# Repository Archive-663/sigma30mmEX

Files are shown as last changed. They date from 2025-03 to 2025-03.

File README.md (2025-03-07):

# Lot no. 018 | Sigma 30mm f1.4 HSM EX Canon EF Mount Conversion

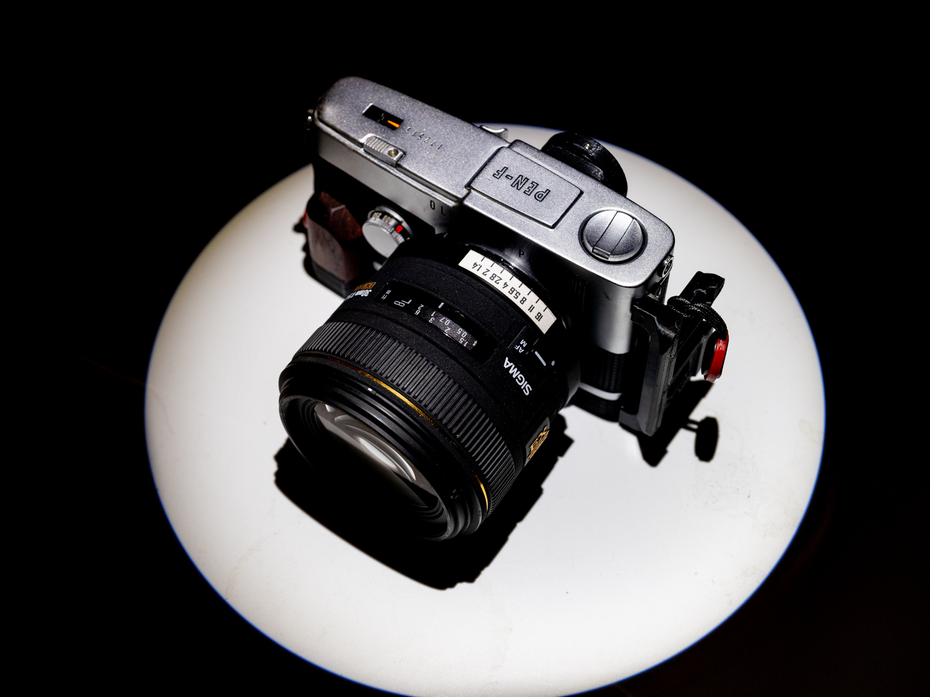
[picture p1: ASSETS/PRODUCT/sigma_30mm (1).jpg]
productShot001

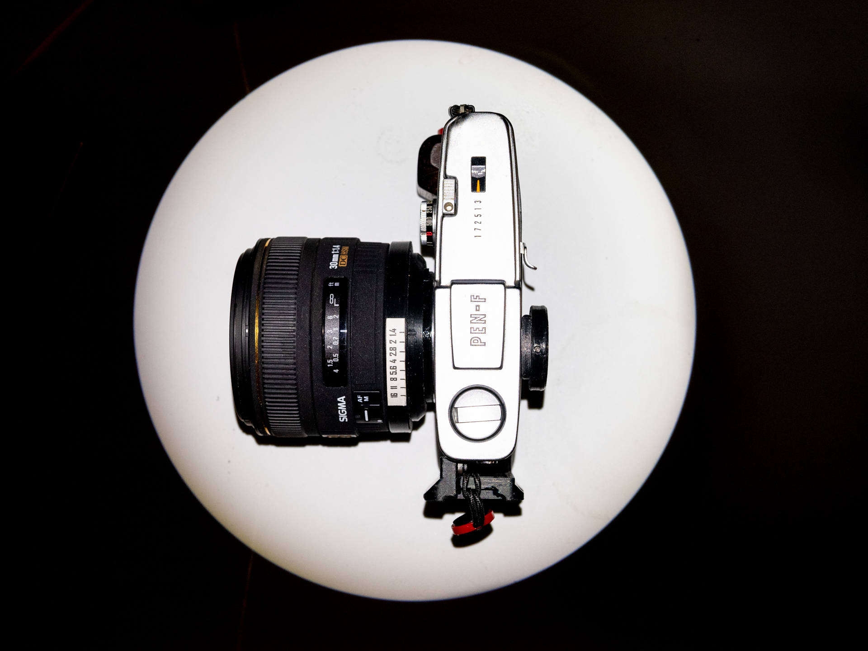
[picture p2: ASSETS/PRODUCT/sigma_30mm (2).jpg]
productShot002


### In this repository:
- Sigma 30mm f1.4 EX HSM Canon EF Aperture Control and Mount Conversion

### Background Story:
My preferred FOV for everyday photography is around 42-45mm. People keep telling me it's the most natural FOV to match our eye's FOV. Yes, we see a lot peripherally, but the main content lies within that 42-45mm FOV on a 135 camera. I've read very good reviews of the 30mm f1.4 EX HSM and I had one on hand from trying to push the low light capabilities of my GH5 with a speedbooster. These days my GH5 has a Rokinon 21mm f1.4 lens stuck to it or the 12-40mm when I need that zoom. In my search for the perfect lens for my Olympus PEN-F half frame camera, I was using an old 28mm f4 for it's size, but I wanted better low light performance as well as wonderful rendering.

Which leads us here. I took apart the Sigma 30mm and drafted some parts to mate to the iris to allow me to control it manually. Then added a PEN-F mount at the approximate correct distance to register inifinity. After getting acceptable focus, I did a quick and dirty F-stop identification mounting the lens on my Sony A7RII and added detents on the lens for these stops. I find 3D printed numbers/lettering pretty bad so I just made a label with the f-stops using the arc length between the stops and the overall throw of the iris. 

I love it so much. It's super sharp on half frame -- something I've found hard to realize with half frame. It's a little unwieldly with the large size of the 30mm but the results are worth it for me.

### What you'll need:
- 9-13x M1.6 x 5mm pan head screws (PETG) or self-tappin screws (ABS or PETG)
- 1x M1.6 tap

### What would be helpful:
- M1.4 drill bit
- M1.8/M2 drill bit
- Micro files
- PTFE synthetic grease

### Printing help:
Filament recommendation:
- ABS
- PETG

Generally, all my designs have chamfers on the print face of the STL. You can reference the supplied 'printOrientationFile.3mf' files for suggested print orientation.

### Assembly help:
Drill holes to their correct tap size before tapping.
- M1.6 requires M1.4 bore followed by an M1.6 tap.
- M1.8 or M2 bore for screw holes that aren't tapped.

Test fit before assembling. Will need to file parts to allow free movement. 

Lightly grease the inside of the mount where the aperture clutch runs.

To assemble correctly, please view the _assembly.stp file for help in parts orientation. If you do not have a CAD program, <a href="https://www.freecad.org/downloads.php" target="_blank">download FreeCAD</a> to view the assembly file and better understand how it should assemble. If using FreeCAD, the naming conventions should carry over and you will be able to see which lens element you need from the various smartphone lenses. (Verified in FreeCAD 0.18) If using something like Solid Edge open the file as an assembly to retain the names of the parts.

### Help support Archive 663 with a dontation or monthly sub



### Samples

#### Film
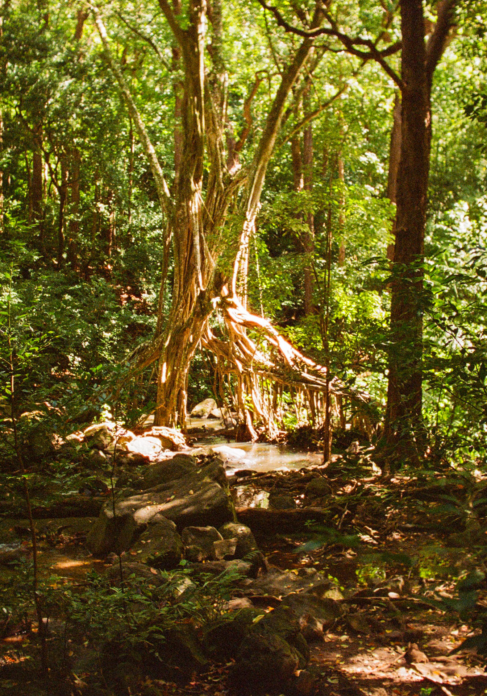
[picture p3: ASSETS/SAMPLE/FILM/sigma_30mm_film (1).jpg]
sampleFilmShot001

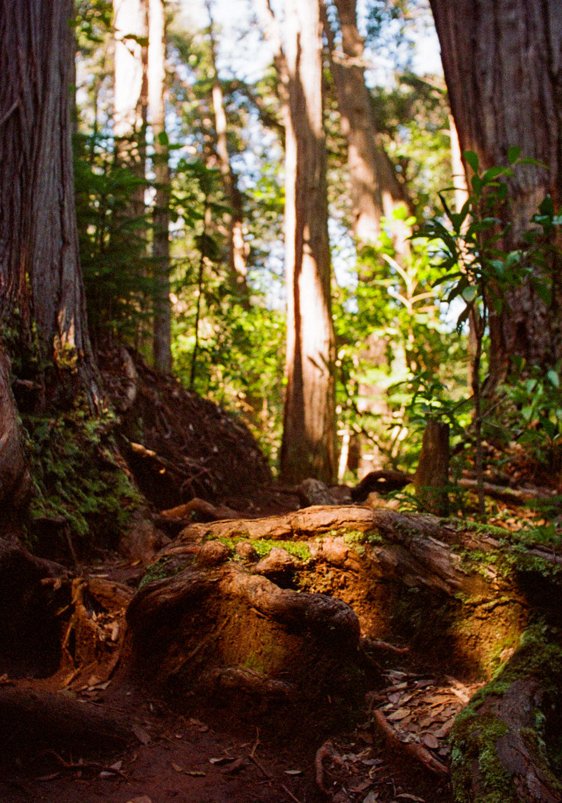
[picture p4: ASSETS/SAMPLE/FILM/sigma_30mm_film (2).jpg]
sampleFilmShot002

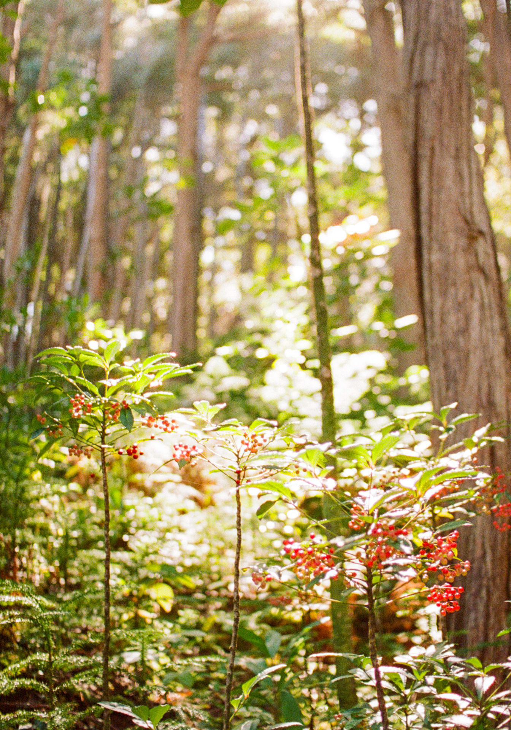
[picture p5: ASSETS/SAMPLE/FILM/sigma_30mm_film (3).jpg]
sampleFilmShot003

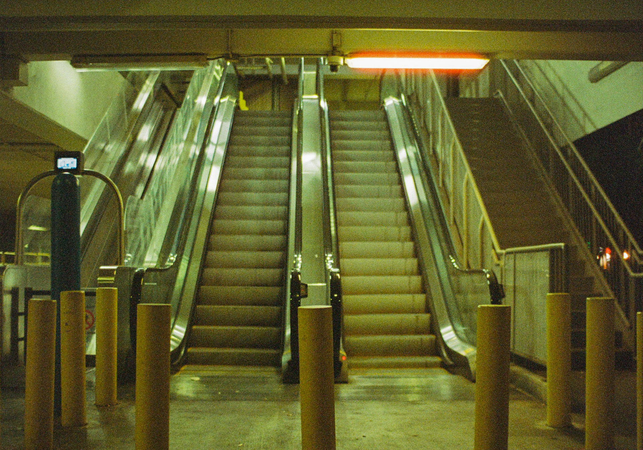
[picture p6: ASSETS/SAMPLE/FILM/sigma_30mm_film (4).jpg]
sampleFilmShot004

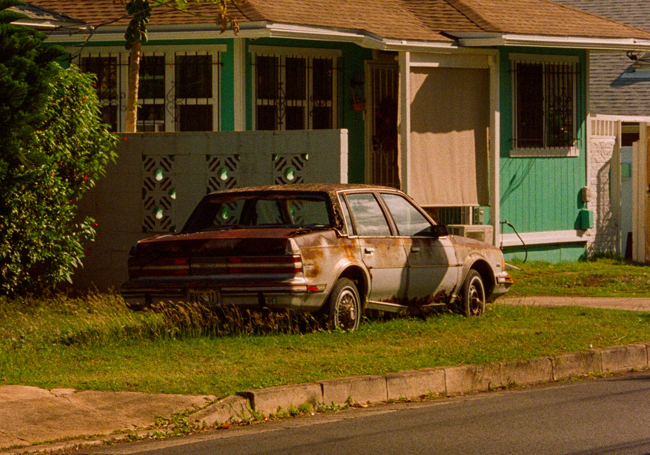
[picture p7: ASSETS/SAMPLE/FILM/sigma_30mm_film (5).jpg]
sampleFilmShot005

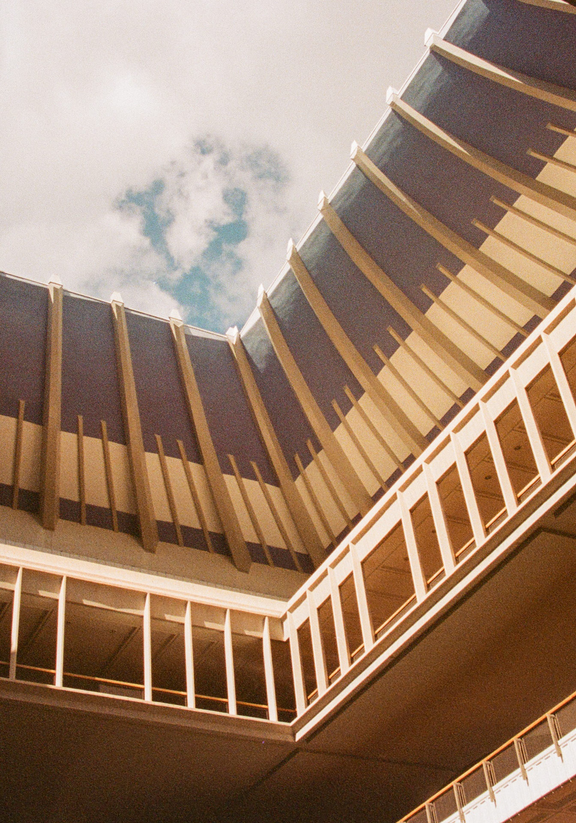
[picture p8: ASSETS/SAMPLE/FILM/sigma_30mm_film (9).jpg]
sampleFilmShot009


#### Digital
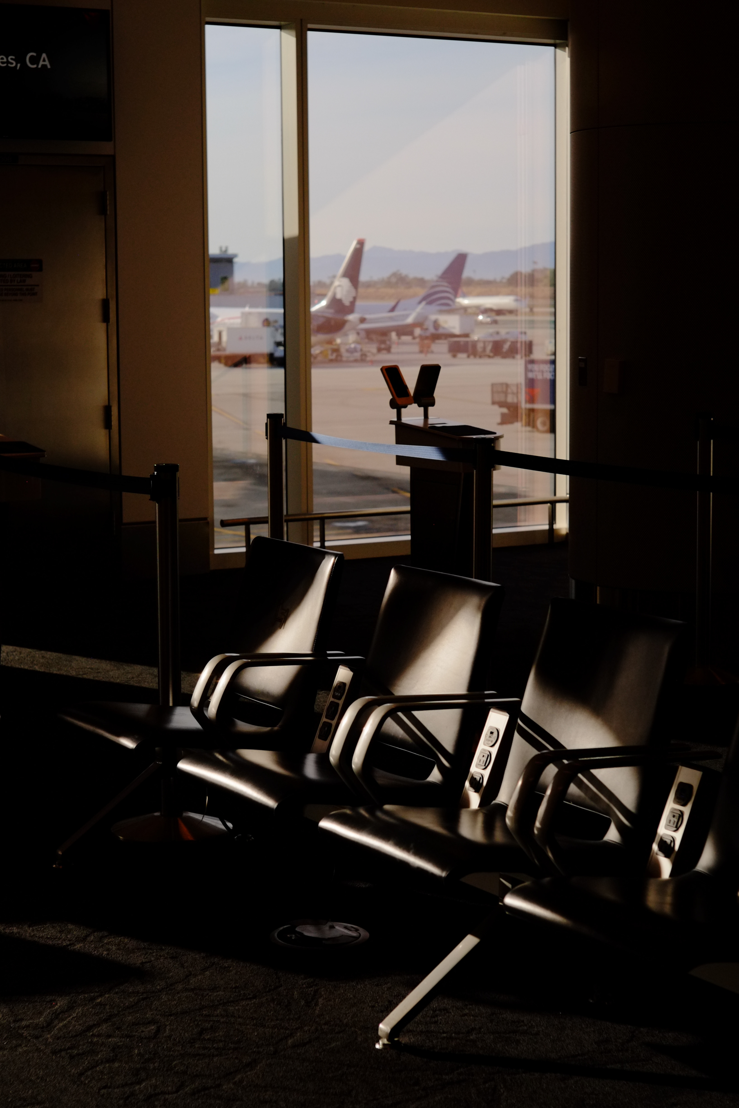
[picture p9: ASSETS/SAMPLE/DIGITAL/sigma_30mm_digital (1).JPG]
sampleDigitalShot001

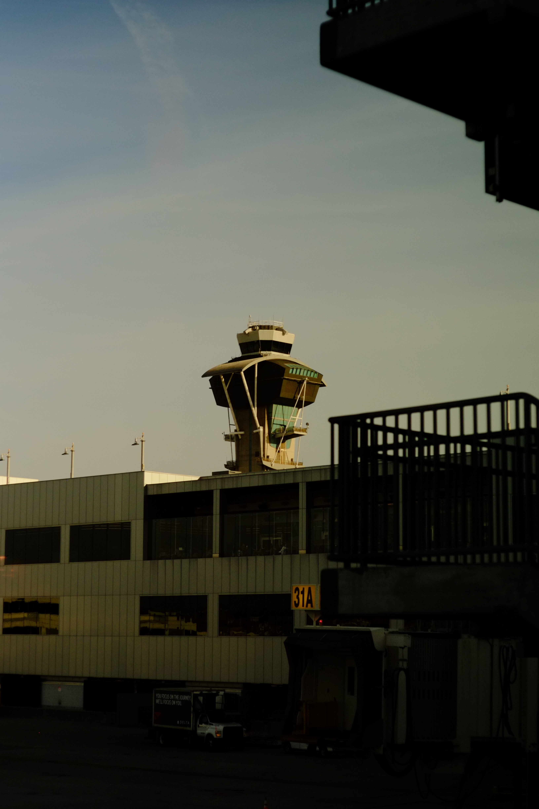
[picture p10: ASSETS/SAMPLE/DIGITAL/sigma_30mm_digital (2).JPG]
sampleDigitalShot002

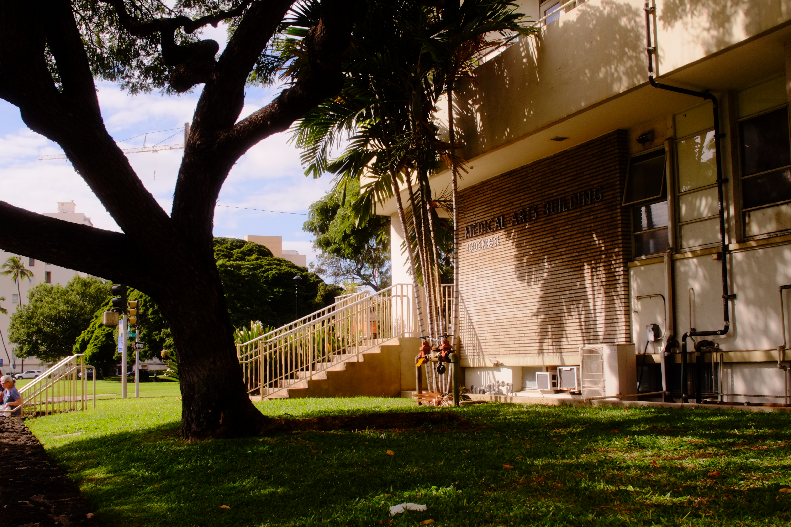
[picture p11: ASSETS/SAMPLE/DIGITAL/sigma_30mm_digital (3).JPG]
sampleDigitalShot003

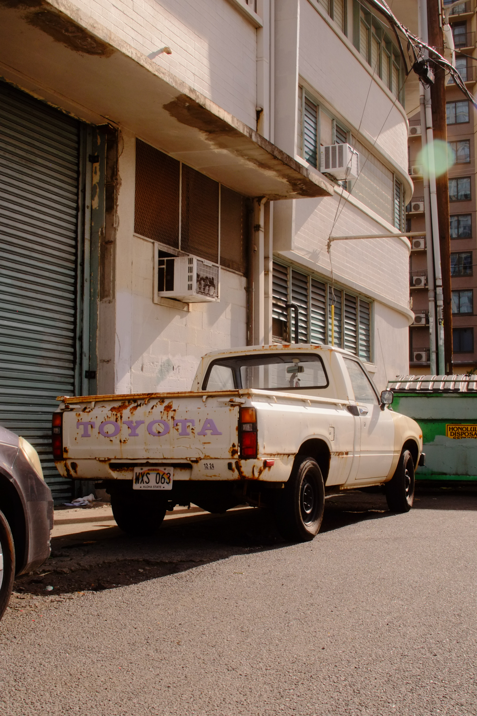
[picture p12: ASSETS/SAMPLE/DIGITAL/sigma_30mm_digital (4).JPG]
sampleDigitalShot004

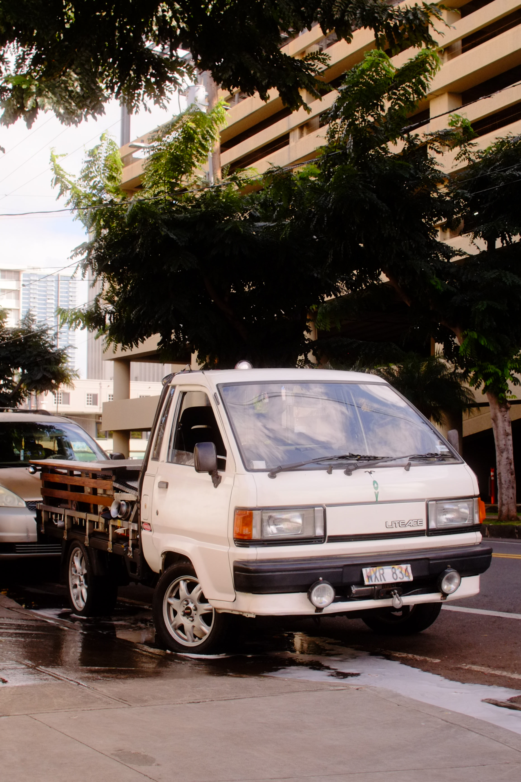
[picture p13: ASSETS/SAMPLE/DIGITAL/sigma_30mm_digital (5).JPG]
sampleDigitalShot005

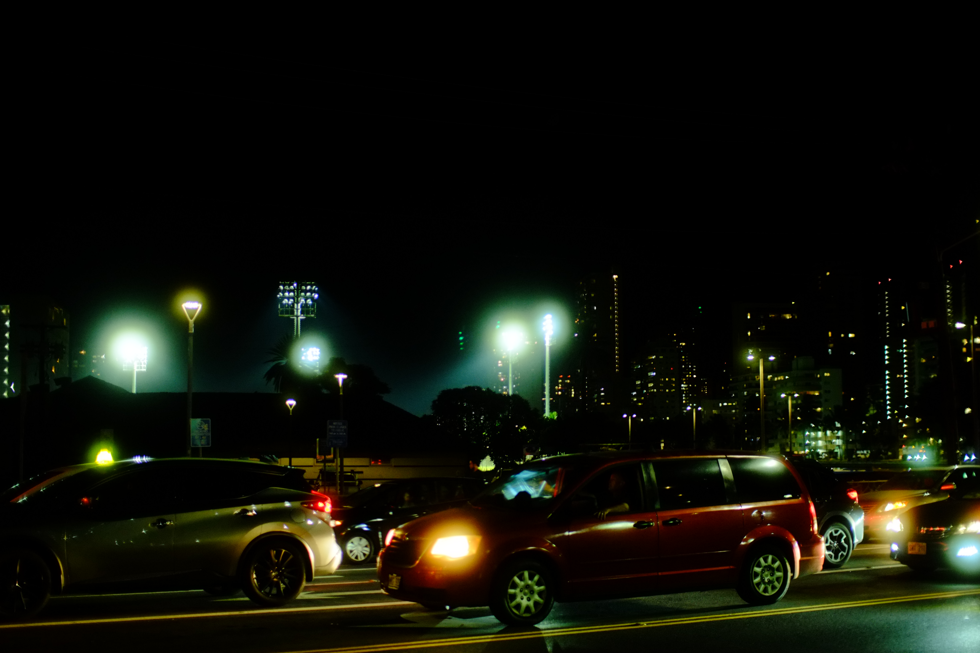
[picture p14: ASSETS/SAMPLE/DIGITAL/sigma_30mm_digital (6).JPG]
sampleDigitalShot006

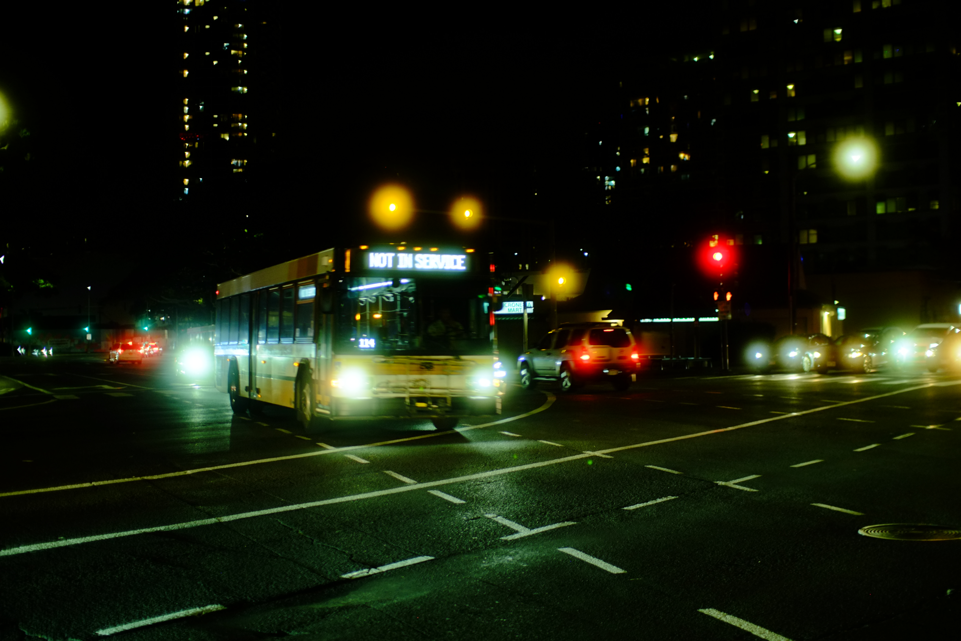
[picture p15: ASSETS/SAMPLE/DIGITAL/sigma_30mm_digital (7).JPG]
sampleDigitalShot007

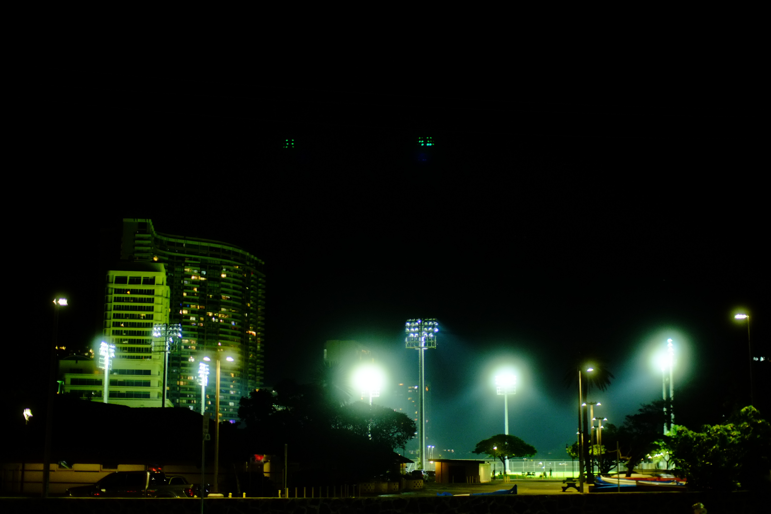
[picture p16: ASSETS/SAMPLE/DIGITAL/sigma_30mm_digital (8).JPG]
sampleDigitalShot008

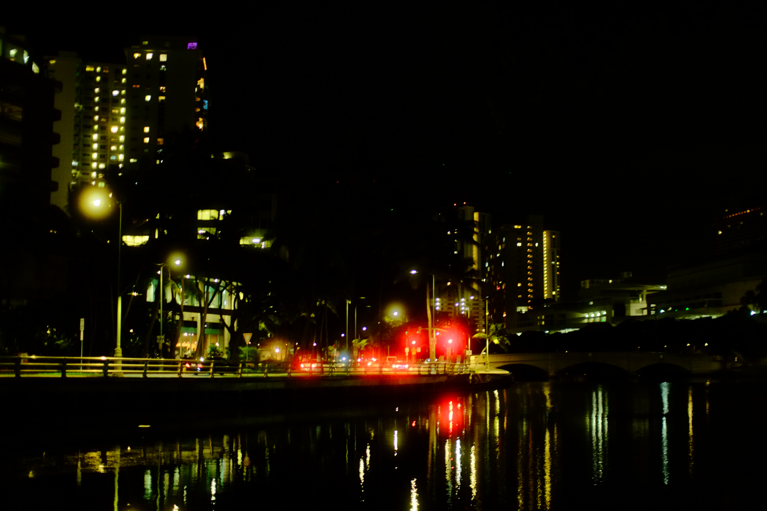
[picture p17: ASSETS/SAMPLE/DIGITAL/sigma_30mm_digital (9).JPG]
sampleDigitalShot009

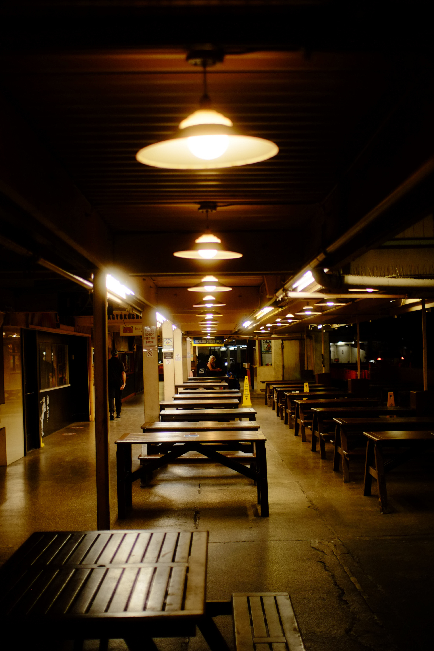
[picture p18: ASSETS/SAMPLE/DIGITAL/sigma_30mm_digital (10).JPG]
sampleDigitalShot010

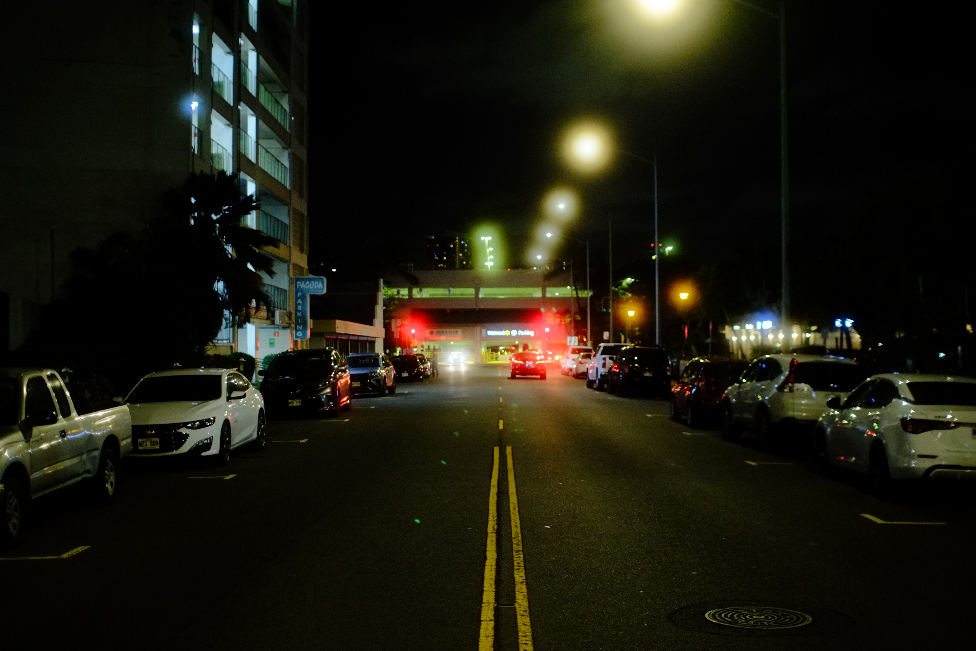
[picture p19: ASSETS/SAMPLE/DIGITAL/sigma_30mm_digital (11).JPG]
sampleDigitalShot011

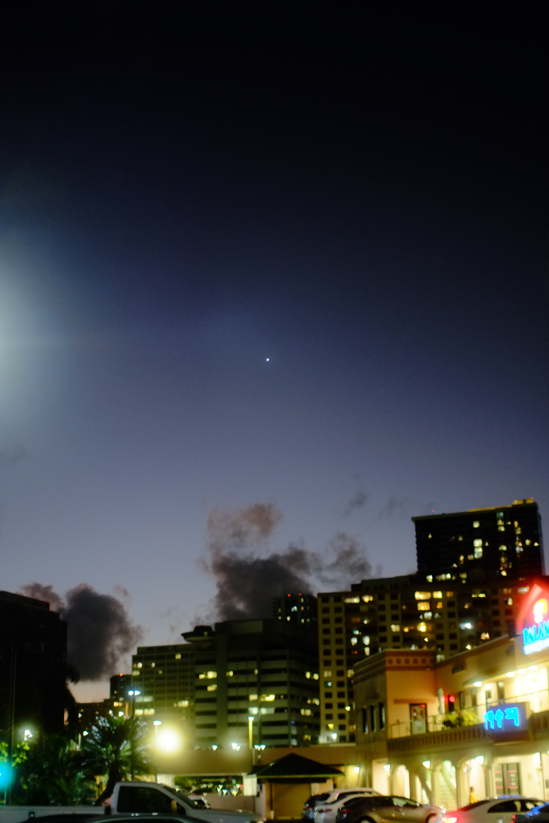
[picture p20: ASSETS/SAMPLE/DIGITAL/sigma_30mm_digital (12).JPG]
sampleDigitalShot012

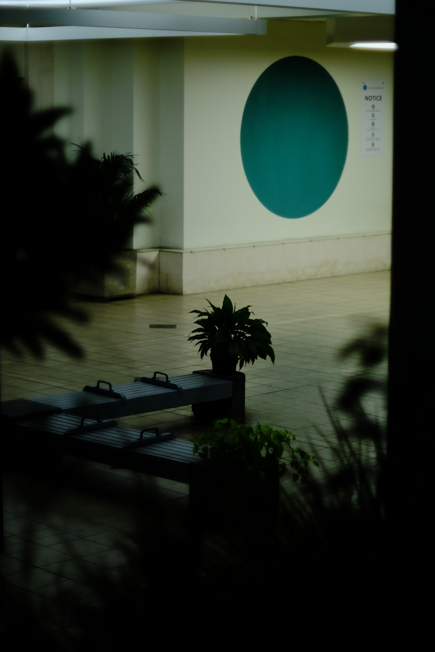
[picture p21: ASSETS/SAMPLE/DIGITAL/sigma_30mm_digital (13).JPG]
sampleDigitalShot013

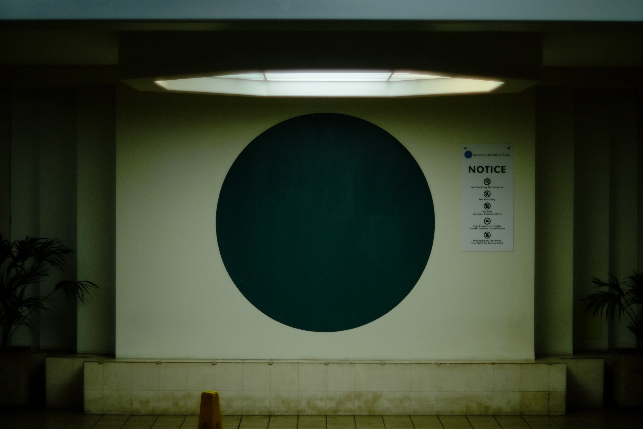
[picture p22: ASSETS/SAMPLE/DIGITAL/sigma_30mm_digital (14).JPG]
sampleDigitalShot014

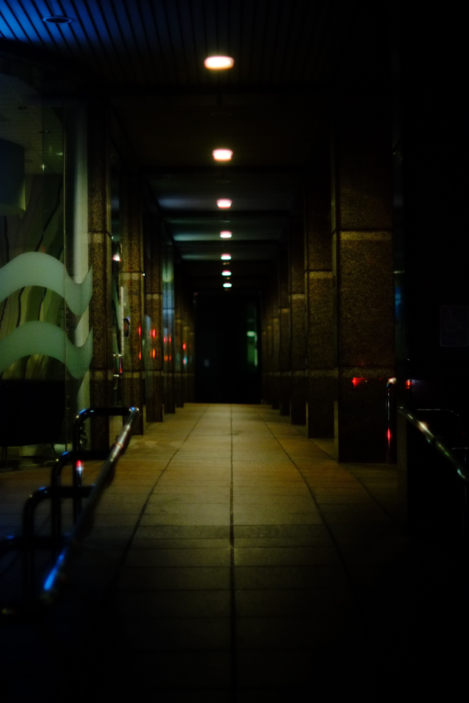
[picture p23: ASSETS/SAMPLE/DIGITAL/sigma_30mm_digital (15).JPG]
sampleDigitalShot015

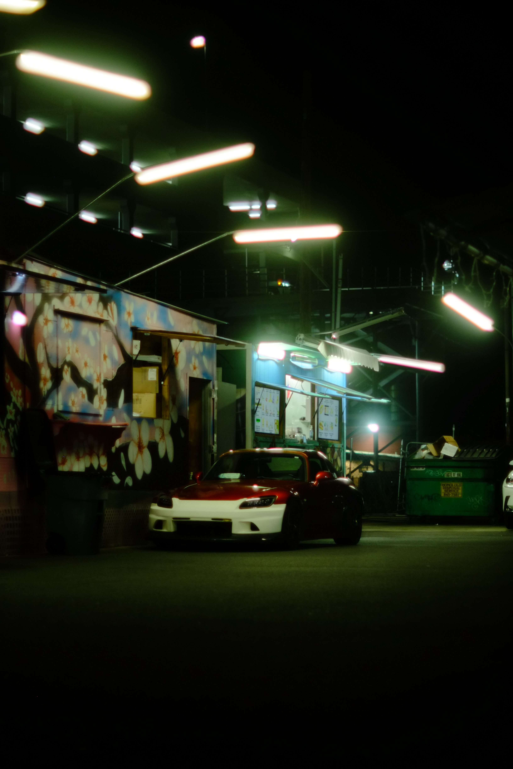
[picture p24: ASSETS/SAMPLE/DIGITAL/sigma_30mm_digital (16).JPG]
sampleDigitalShot016


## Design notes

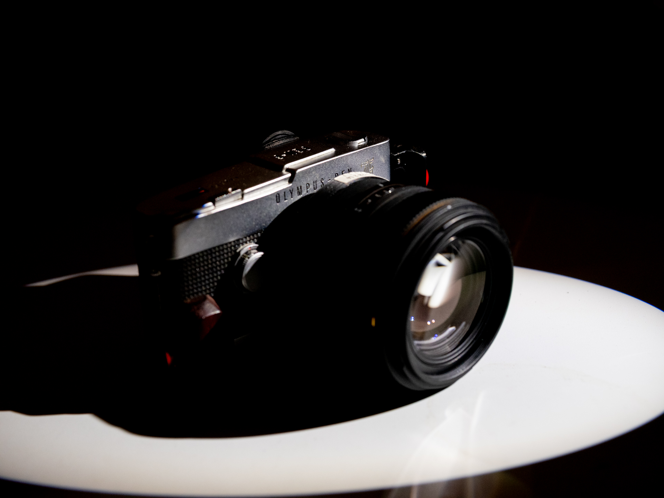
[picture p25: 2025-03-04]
ASSETS/PRODUCT/sigma_30mm (3).jpg

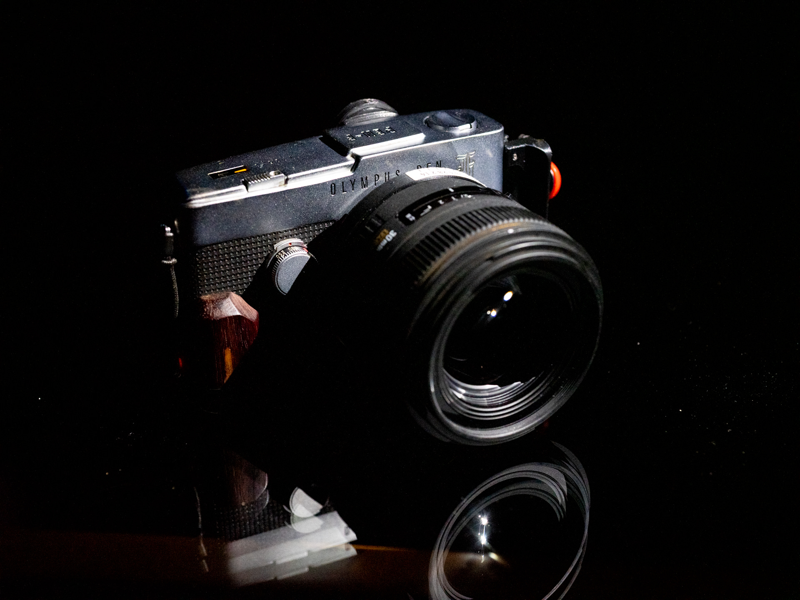
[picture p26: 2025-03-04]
ASSETS/PRODUCT/sigma_30mm (4).jpg

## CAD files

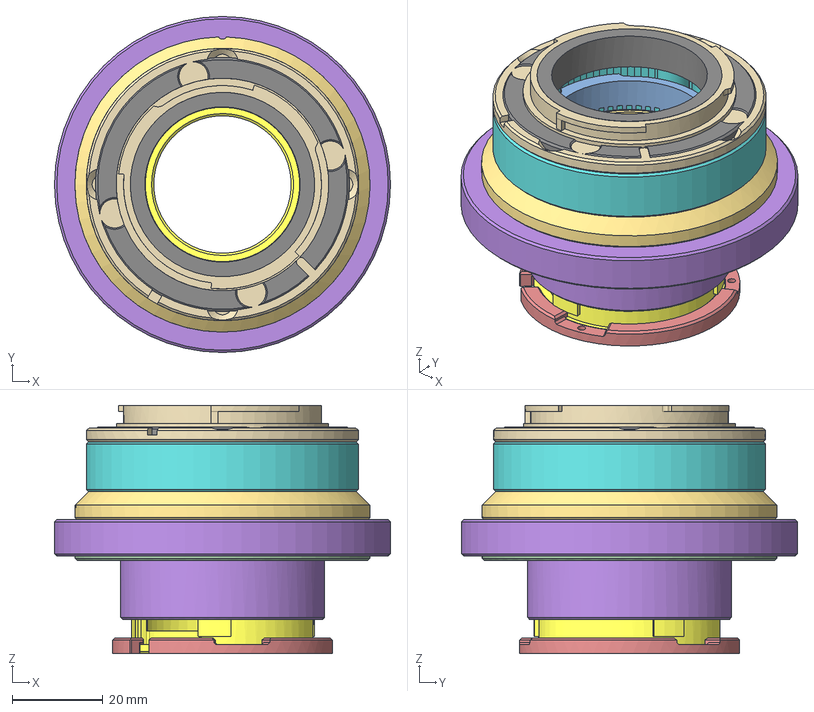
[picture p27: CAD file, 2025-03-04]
STEP/sigma30mm_PENF_assembly.stp
74.0 x 74.0 x 54.7 mm
sigma30mm_PENF_mainBody
sigma30mm_PENF_mainBody_apertureRing
sigma30mm_PENF_mainBody_flangeUpper
sigma30mm_PENF_mainBody_apertureLock
sigma30mm_PENF_mainBody_flangeLower
sigma30mm_PENF_mainBody_apertureClutch
sigma30mm_PENF_mainBody_flangeUpper_sonyE
sigma30mm_PENF_mainBody_flange_sonyE
sigma30mm_PENF_mainBody_flange_fujiX
sigma30mm_PENF_mainBody_flangeUpper_fujiX

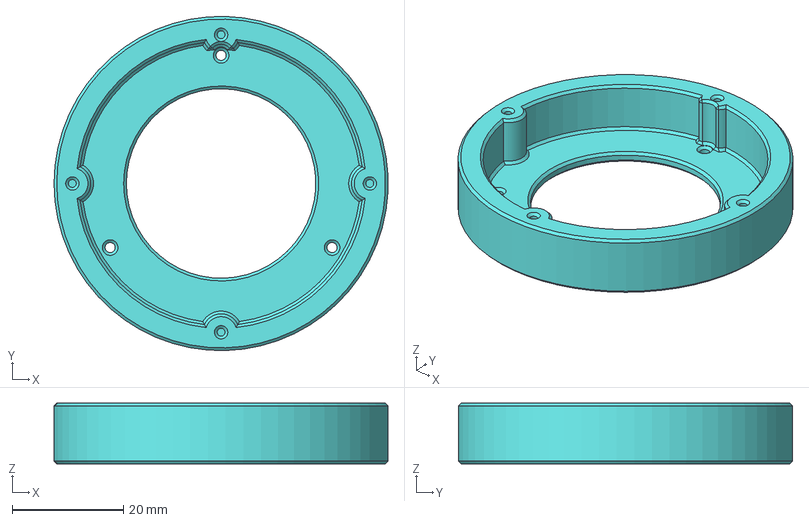
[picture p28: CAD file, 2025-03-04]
STEP/sigma30mm_PENF_mainBody_flangeUpper_sonyE.stp
60.0 x 60.0 x 10.9 mm

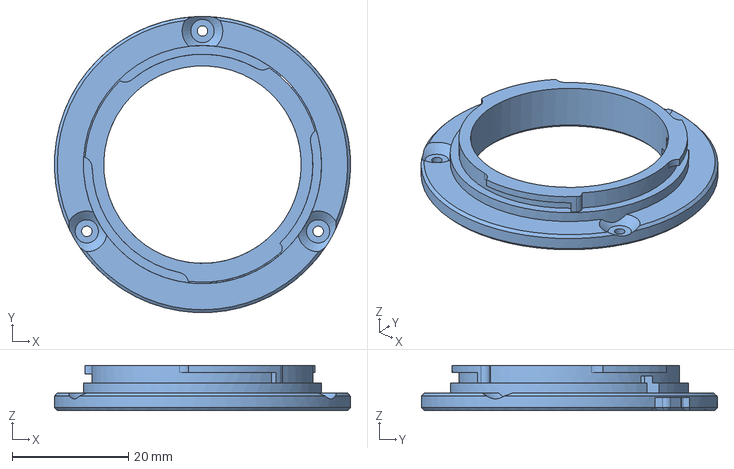
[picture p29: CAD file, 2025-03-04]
STEP/sigma30mm_PENF_mainBody_flangeUpper.stp
51.0 x 51.0 x 7.75 mm

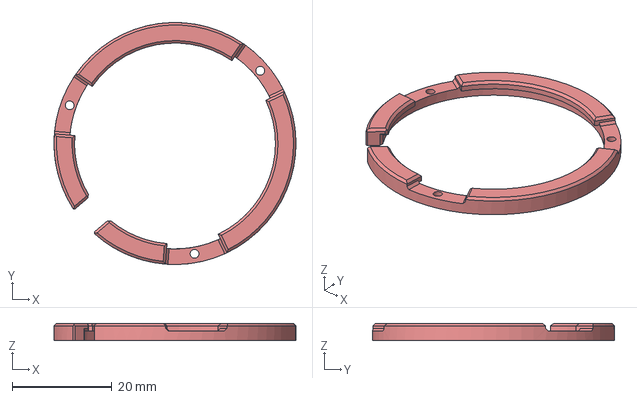
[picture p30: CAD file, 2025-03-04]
STEP/sigma30mm_PENF_mainBody_apertureLock.stp
48.5 x 48.5 x 3.50 mm

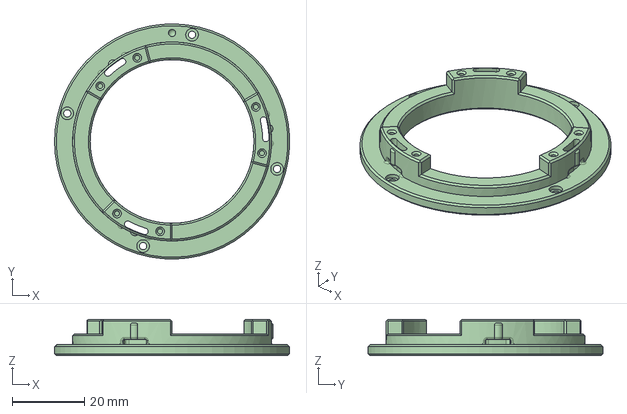
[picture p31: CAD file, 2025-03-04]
STEP/sigma30mm_PENF_mainBody.stp
65.0 x 65.0 x 10.0 mm

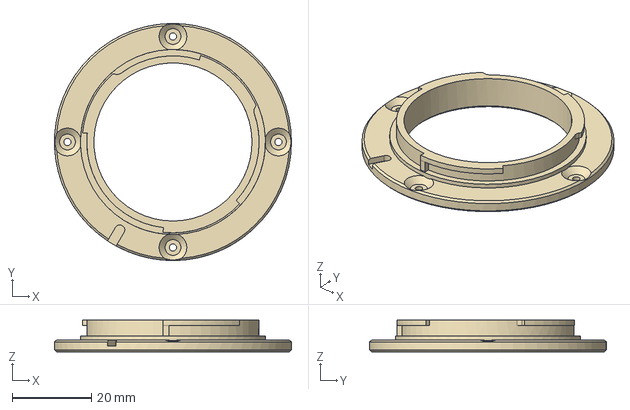
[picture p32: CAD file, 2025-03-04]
STEP/sigma30mm_PENF_mainBody_flange_sonyE.stp
60.0 x 60.0 x 8.00 mm

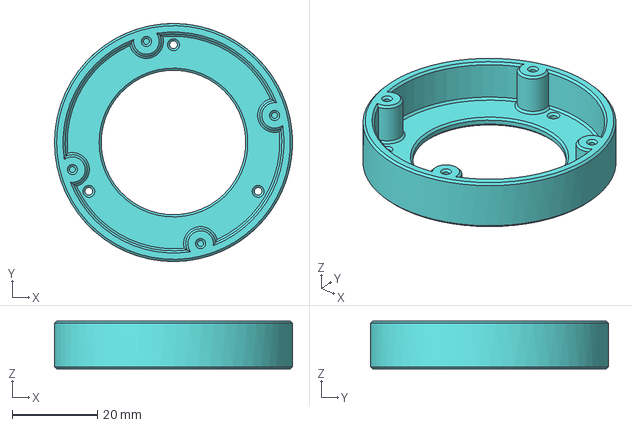
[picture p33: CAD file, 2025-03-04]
STEP/sigma30mm_PENF_mainBody_flangeUpper_fujiX.stp
56.0 x 56.0 x 11.2 mm

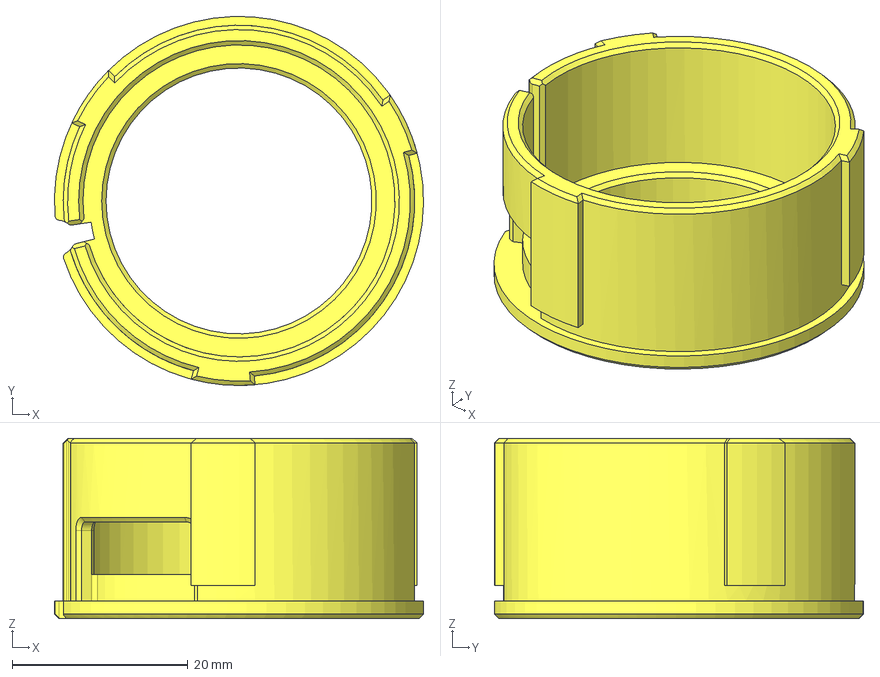
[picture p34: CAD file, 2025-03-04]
STEP/sigma30mm_PENF_mainBody_apertureClutch.stp
42.0 x 42.0 x 20.5 mm

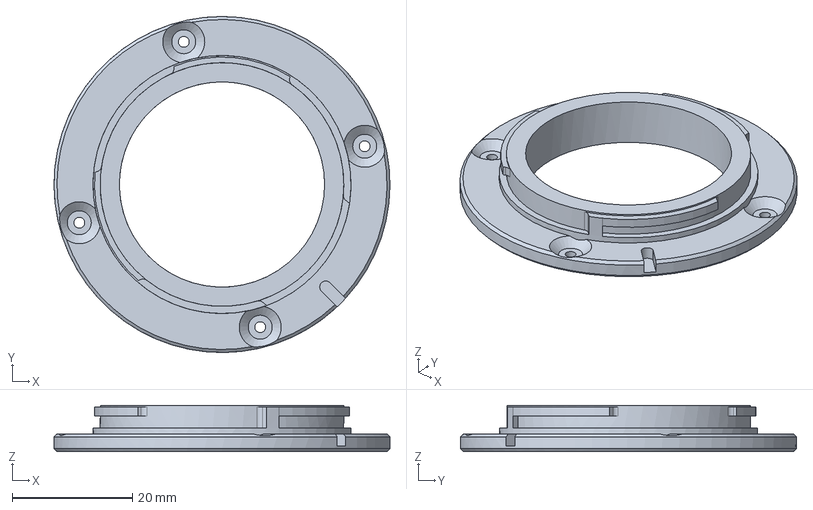
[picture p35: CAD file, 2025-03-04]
STEP/sigma30mm_PENF_mainBody_flange_fujiX.stp
56.0 x 56.0 x 7.75 mm

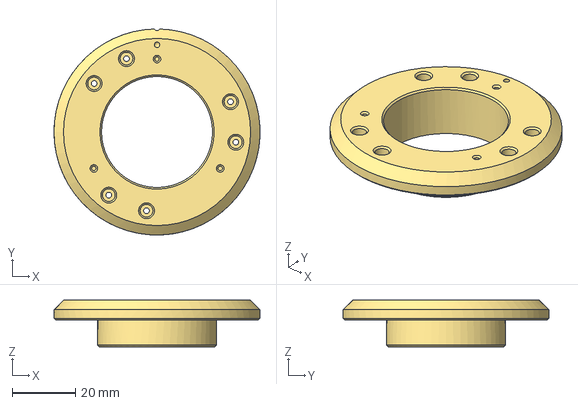
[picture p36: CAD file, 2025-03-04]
STEP/sigma30mm_PENF_mainBody_flangeLower.stp
65.0 x 65.0 x 14.7 mm

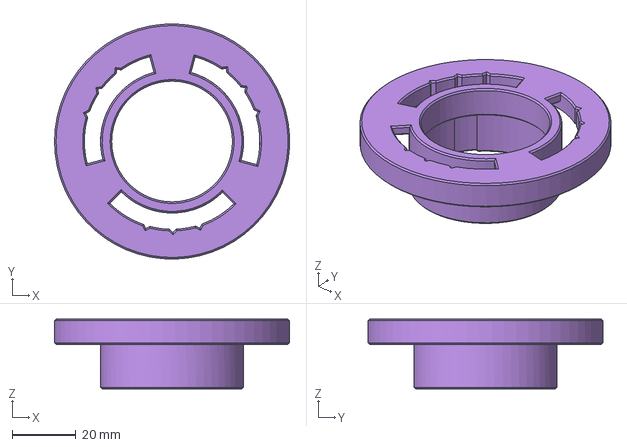
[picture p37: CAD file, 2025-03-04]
STEP/sigma30mm_PENF_mainBody_apertureRing.stp
73.9 x 74.0 x 22.0 mm

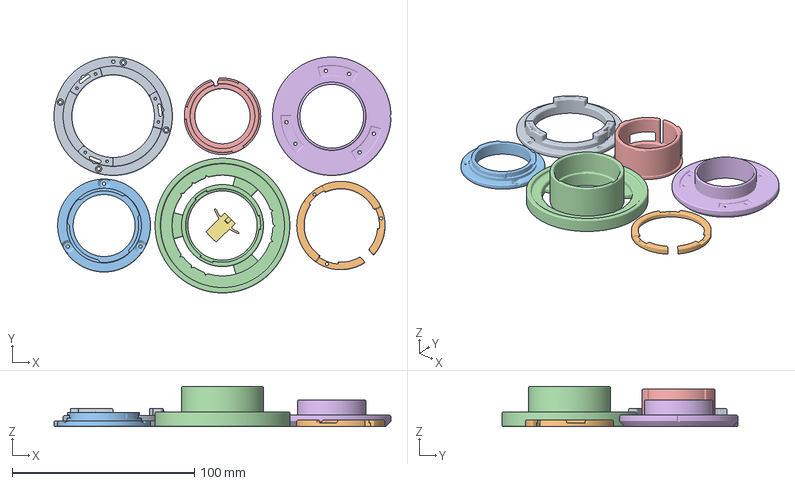
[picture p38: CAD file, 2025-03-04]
STL/sigma30mm_PENF_printOrientation.3mf
185.0 x 129.5 x 22.0 mm
sigma30mm_PENF_mainBody.stl
sigma30mm_PENF_mainBody_apertureLock.stl
sigma30mm_PENF_mainBody_flangeUpper.stl
sigma30mm_PENF_mainBody_apertureRing.stl
sigma30mm_PENF_mainBody_apertureClutch.stl
sigma30mm_PENF_mainBody_flangeLower.stl
mountLensBase_lensLock_extended_PENF.stl

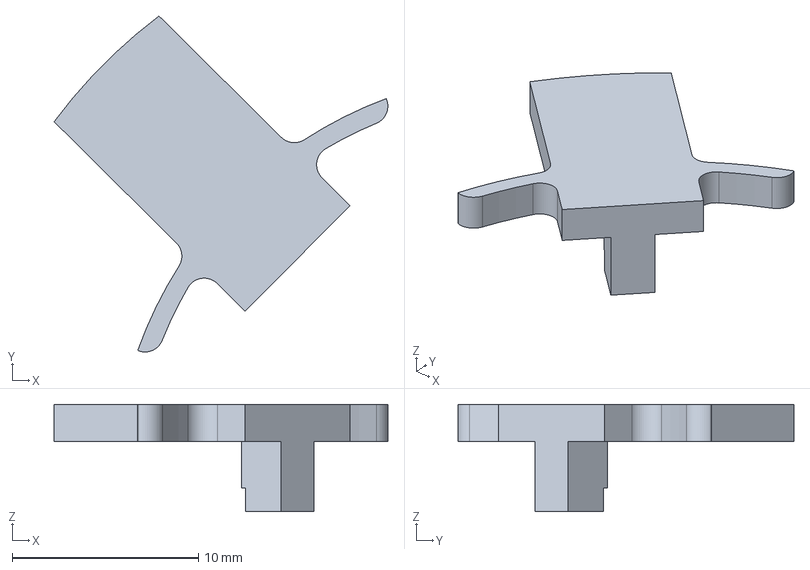
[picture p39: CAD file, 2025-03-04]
STEP/mountLensBase_lensLock_extended_PENF.stp
17.9 x 18.1 x 5.75 mm

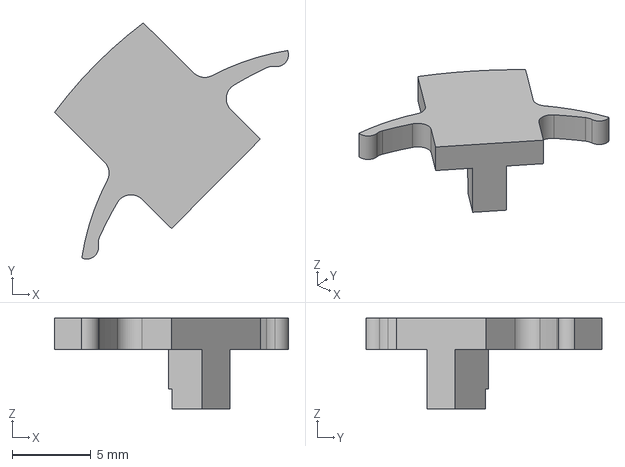
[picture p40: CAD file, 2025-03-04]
STEP/mountLensBase_lensLock_PENF.stp
14.8 x 15.0 x 5.75 mm

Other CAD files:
STL/mountLensBase_lensLock_PENF.stl
STL/mountLensBase_lensLock_extended_PENF.stl
STL/sigma30mm_PENF_mainBody.stl
STL/sigma30mm_PENF_mainBody_apertureClutch.stl
STL/sigma30mm_PENF_mainBody_apertureLock.stl
STL/sigma30mm_PENF_mainBody_apertureRing.stl
STL/sigma30mm_PENF_mainBody_flangeLower.stl
STL/sigma30mm_PENF_mainBody_flangeUpper.stl
STL/sigma30mm_PENF_mainBody_flangeUpper_fujiX.stl
STL/sigma30mm_PENF_mainBody_flangeUpper_sonyE.stl
STL/sigma30mm_PENF_mainBody_flange_fujiX.stl
STL/sigma30mm_PENF_mainBody_flange_sonyE.stl
